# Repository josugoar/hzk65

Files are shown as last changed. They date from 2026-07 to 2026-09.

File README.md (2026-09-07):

# hzk65

<p align="center">
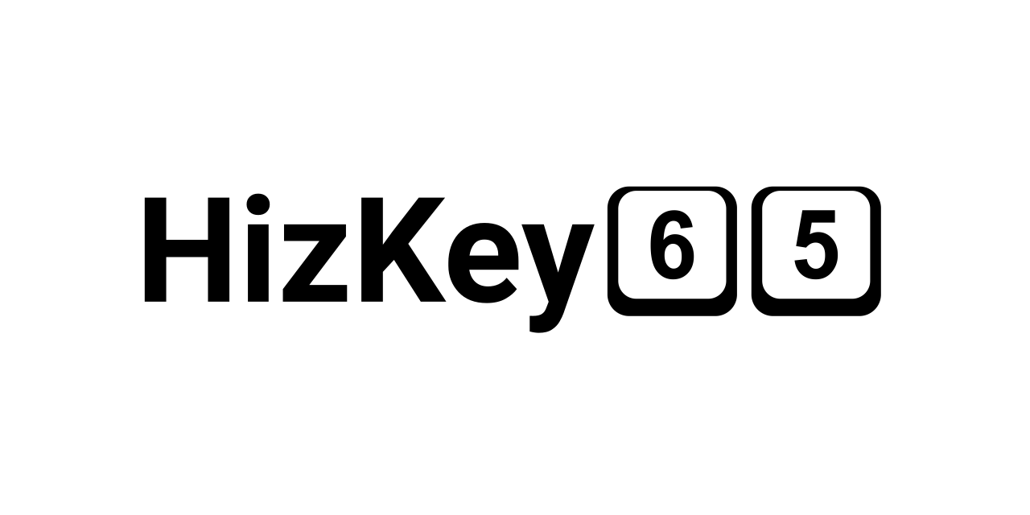
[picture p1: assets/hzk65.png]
hzk65
  
</p>

<h1></h1>

> Modular assembly 65% keyboard

HizKey65 ([/is̻ki/](https://hiztegiak.elhuyar.eus/eu/hizki)) is a modular assembly 65% keyboard with a socketed controller, hot-swap switch sockets, sandwich-mounted case and ANSI layout.

Built with [KiCad](https://www.kicad.org/) and [FreeCAD](https://www.freecad.org/) and manufactured by [JLC Digital Manufacturing](https://jlcpcb.com/).

> [!NOTE]
> Enclose the controller in an acrylic housing or use conformal coating for enhanced protection

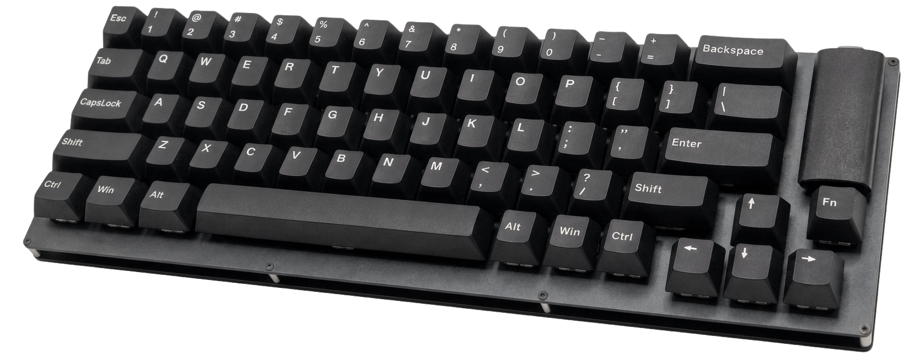
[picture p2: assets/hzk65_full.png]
hzk65_full


## Latest revisions

- hzk65: for Cherry MX compatible switches

  - Rev. A (Hotswappable)

## Layout

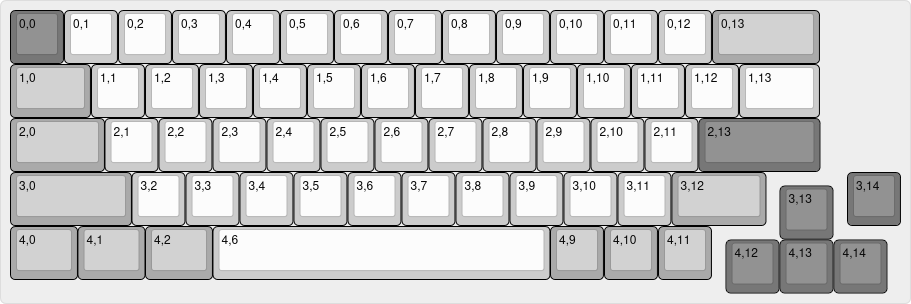
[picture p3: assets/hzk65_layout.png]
hzk65_layout

*[KLE layout](https://www.keyboard-layout-editor.com/##@@_c=%23777777%3B&=0,0&_c=%23cccccc%3B&=0,1&=0,2&=0,3&=0,4&=0,5&=0,6&=0,7&=0,8&=0,9&=0,10&=0,11&=0,12&_c=%23aaaaaa&w:2%3B&=0,13%3B&@_w:1.5%3B&=1,0&_c=%23cccccc%3B&=1,1&=1,2&=1,3&=1,4&=1,5&=1,6&=1,7&=1,8&=1,9&=1,10&=1,11&=1,12&_w:1.5%3B&=1,13%3B&@_c=%23aaaaaa&w:1.75%3B&=2,0&_c=%23cccccc%3B&=2,1&=2,2&=2,3&=2,4&=2,5&=2,6&=2,7&=2,8&=2,9&=2,10&=2,11&_c=%23777777&w:2.25%3B&=2,13%3B&@_c=%23aaaaaa&w:2.25%3B&=3,0&_c=%23cccccc%3B&=3,2&=3,3&=3,4&=3,5&=3,6&=3,7&=3,8&=3,9&=3,10&=3,11&_c=%23aaaaaa&w:1.75%3B&=3,12&_x:1.5&c=%23777777%3B&=3,14%3B&@_y:-0.75&x:14.25%3B&=3,13%3B&@_y:-0.25&c=%23aaaaaa&w:1.25%3B&=4,0&_w:1.25%3B&=4,1&_w:1.25%3B&=4,2&_c=%23cccccc&w:6.25&%2F_rs:180%3B&=4,6&_c=%23aaaaaa%3B&=4,9&=4,10&=4,11%3B&@_y:-0.75&x:13.25&c=%23777777%3B&=4,12&=4,13&=4,14)*

## PCB

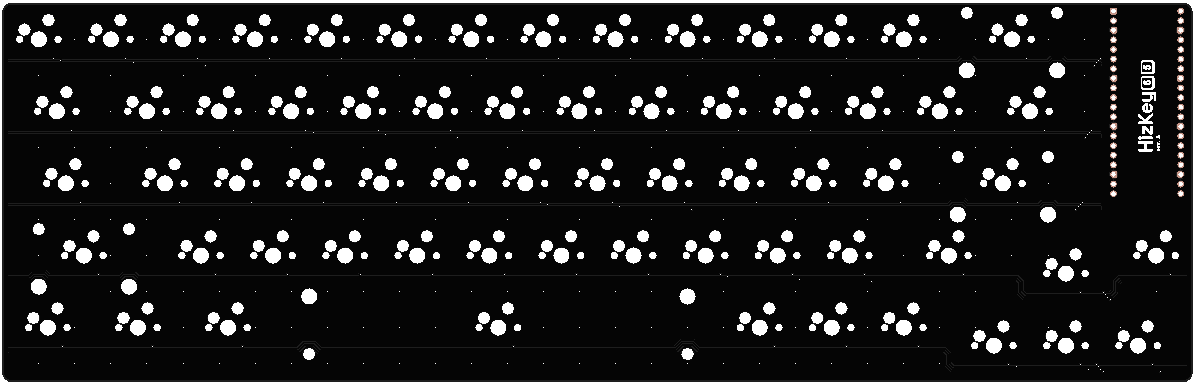
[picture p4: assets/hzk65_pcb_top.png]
hzk65_pcb_top

*Top view*

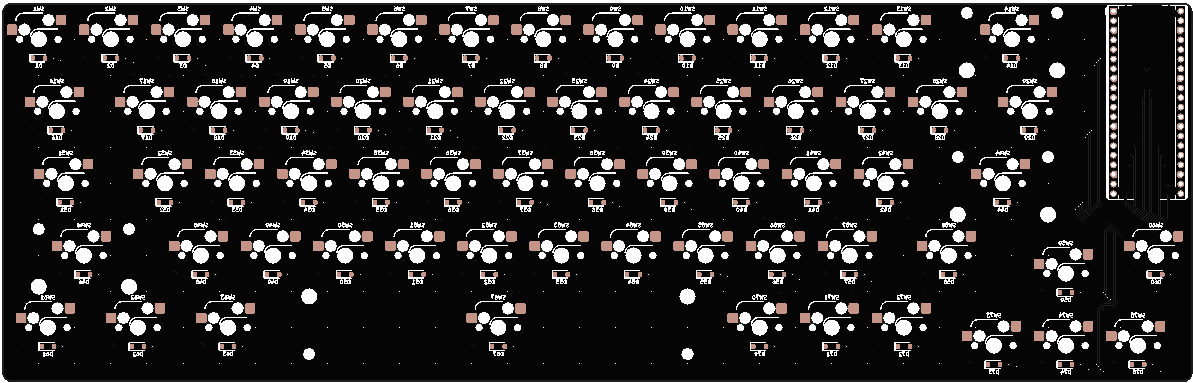
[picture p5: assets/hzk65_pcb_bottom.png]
hzk65_pcb_bottom

*Bottom view*

## Assembly

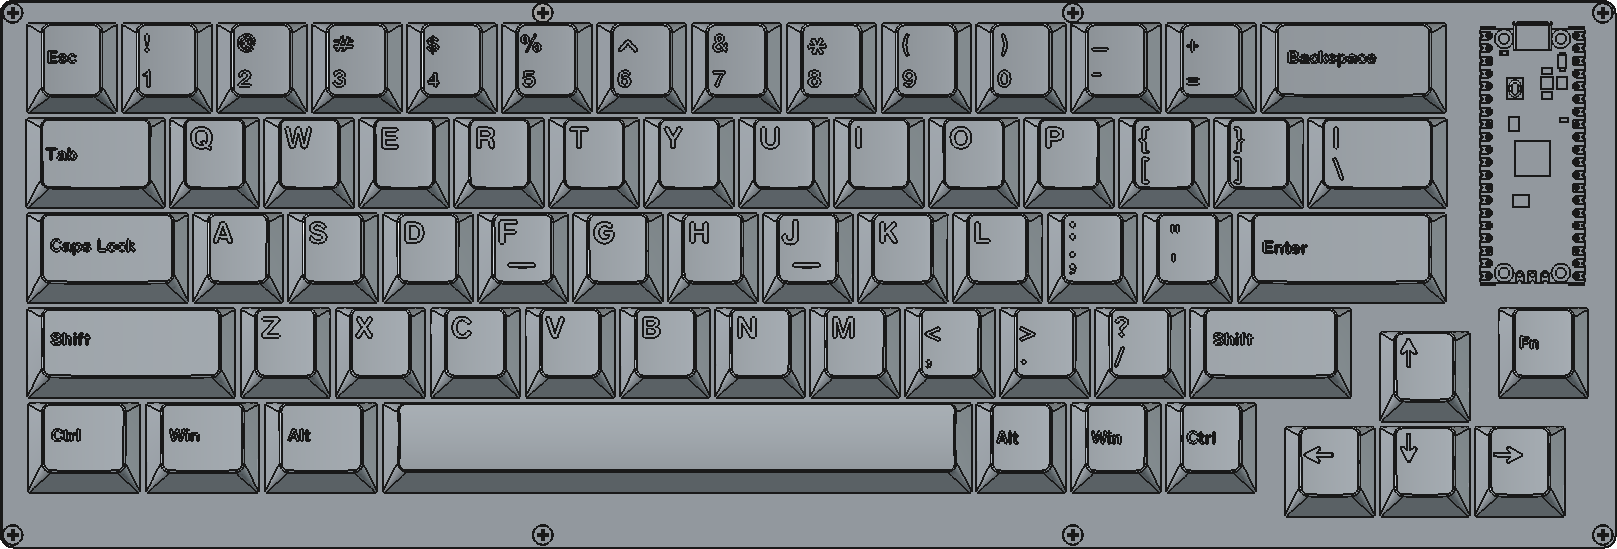
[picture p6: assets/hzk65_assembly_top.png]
hzk65_assembly_top

*Top view*

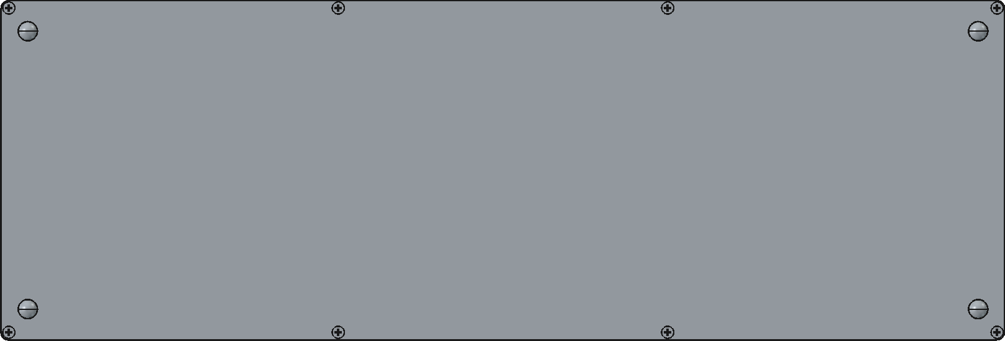
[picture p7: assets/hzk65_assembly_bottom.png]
hzk65_assembly_bottom

*Bottom view*

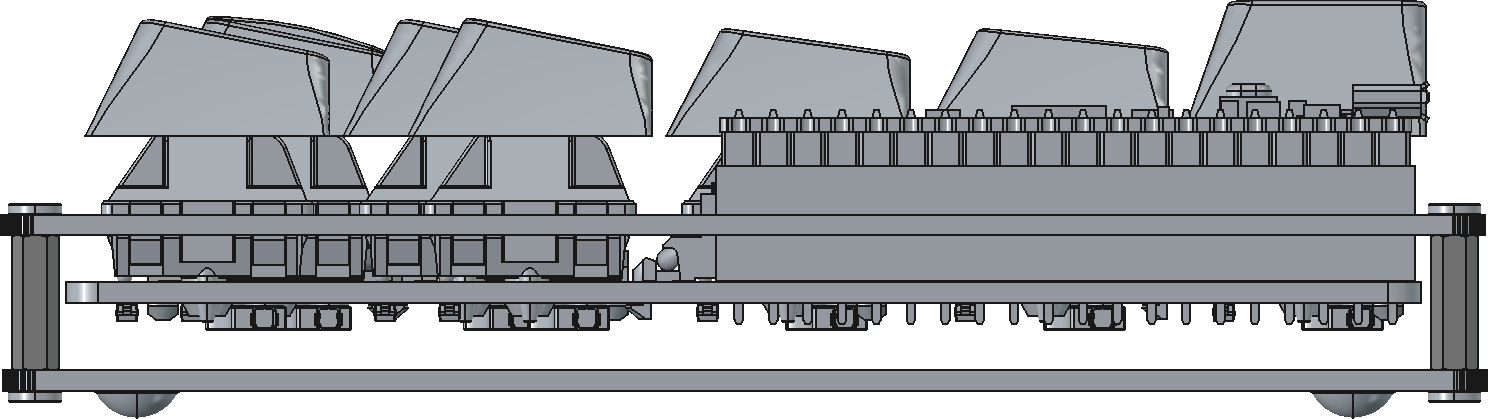
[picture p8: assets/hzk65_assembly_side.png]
hzk65_assembly_side

*Side view*

## Credits

- [CherryMx](https://github.com/hineybush/CherryMX): MX profile keycap 3D models

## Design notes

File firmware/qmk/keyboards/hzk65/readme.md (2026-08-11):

# hzk65

*Modular assembly 65% keyboard*

* Keyboard Maintainer: [Josu](https://github.com/josugoar)
* Hardware Supported: *hzk65*
* Hardware Availability: *https://github.com/josugoar/hzk65*

Make example for this keyboard (after setting up your build environment):

    make hzk65:default

Flashing example for this keyboard:

    make hzk65:default:flash

See the [build environment setup](https://docs.qmk.fm/#/getting_started_build_tools) and the [make instructions](https://docs.qmk.fm/#/getting_started_make_guide) for more information. Brand new to QMK? Start with our [Complete Newbs Guide](https://docs.qmk.fm/#/newbs).

> [!NOTE]
> The hzk65 keyboard directory must be copied to the [qmk_firmware](https://github.com/qmk/qmk_firmware) source tree for compilation

## Bootloader

Enter the bootloader in 3 ways:

* **Bootmagic reset**: Hold down the key at (0,0) in the matrix (usually the top left key or Escape) and plug in the keyboard
* **Physical reset button**: Briefly press the button on the back of the PCB - some may have pads you must short instead
* **Keycode in layout**: Press the key mapped to `QK_BOOT` if it is available

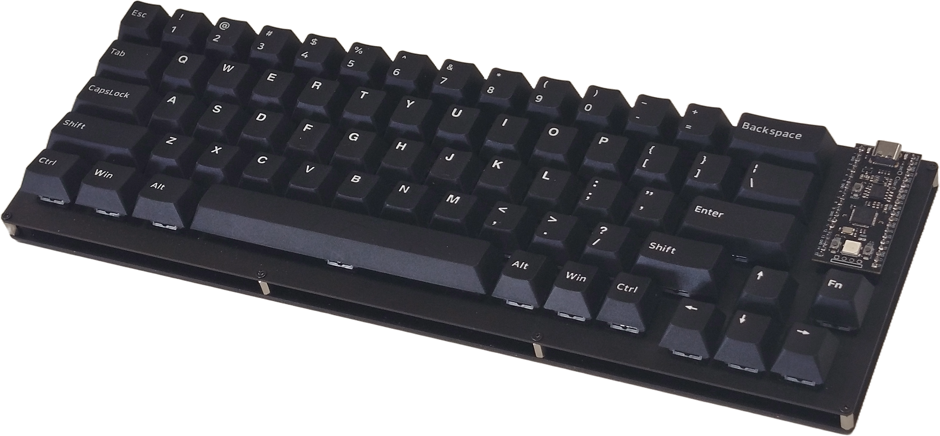
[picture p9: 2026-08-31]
assets/hzk65_pov.png

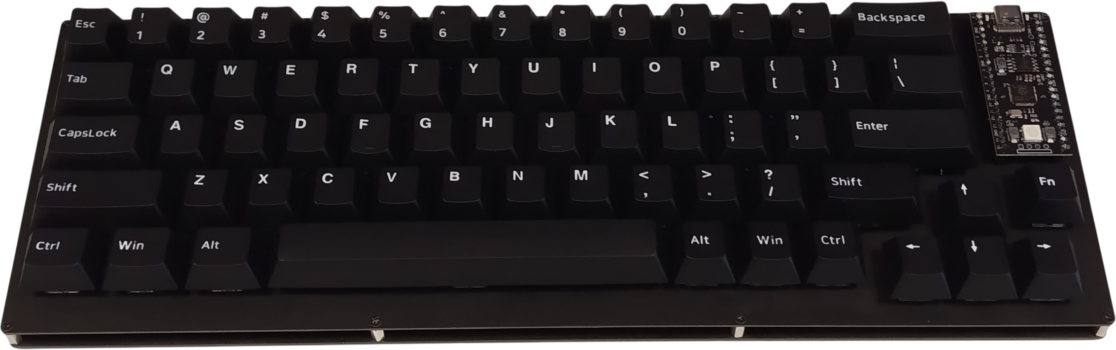
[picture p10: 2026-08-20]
assets/hzk65_top.png

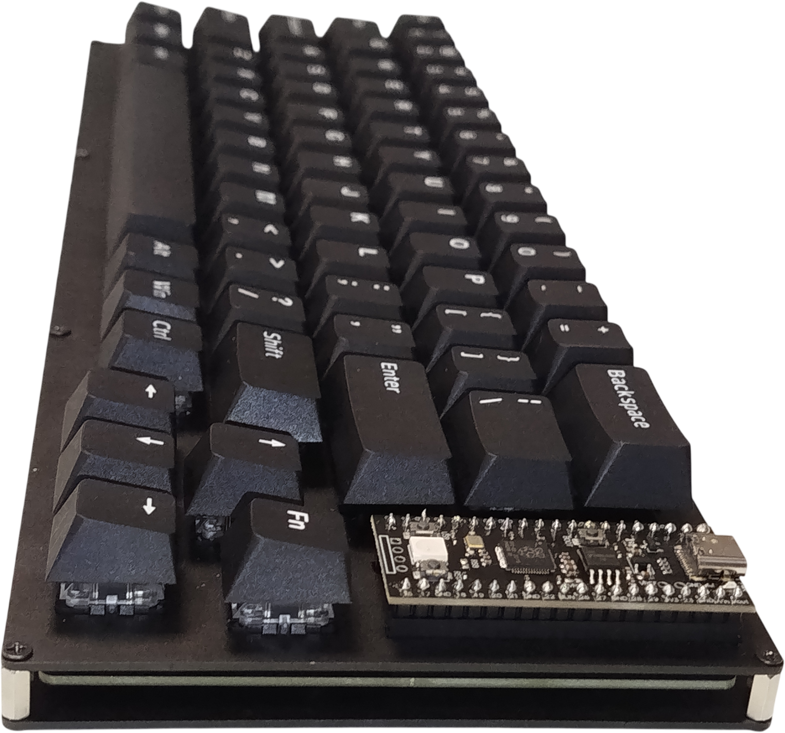
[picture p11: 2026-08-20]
assets/hzk65_side.png

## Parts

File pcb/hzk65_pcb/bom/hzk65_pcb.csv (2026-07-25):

Reference | Qty | Value | DNP | Exclude from BOM | Exclude from Board | Footprint | Datasheet
A1 | 1 | RaspberryPi_Pico |  |  |  | Module:RaspberryPi_Pico_Common_THT | https://datasheets.raspberrypi.com/pico/pico-datasheet.pdf
D1,D2,D3,D4,D5,D6,D7,D8,D9,D10,D11,D12,D13,D14,D16,D17,D18,D19,D20,D21,D22,D23,D24,D25,D26,D27,D28,D29,D31,D32,D33,D34,D35,D36,D37,D38,D39,D40,D41,D42,D44,D46,D48,D49,D50,D51,D52,D53,D54,D55,D56,D57,D58,D59,D60,D61,D62,D63,D67,D70,D71,D72,D73,D74,D75 | 65 | 1N4148 |  |  |  | Diode_SMD:D_SOD-123 | https://assets.nexperia.com/documents/data-sheet/1N4148_1N4448.pdf
SW1,SW2,SW3,SW4,SW5,SW6,SW7,SW8,SW9,SW10,SW11,SW12,SW13,SW17,SW18,SW19,SW20,SW21,SW22,SW23,SW24,SW25,SW26,SW27,SW28,SW32,SW33,SW34,SW35,SW36,SW37,SW38,SW39,SW40,SW41,SW42,SW48,SW49,SW50,SW51,SW52,SW53,SW54,SW55,SW56,SW57,SW59,SW60,SW70,SW71,SW72,SW73,SW74,SW75 | 54 | SW_Push |  |  |  | Switch_Keyboard_Hotswap_Kailh:SW_Hotswap_Kailh_MX_1.00u
SW14 | 1 | SW_Push |  |  |  | Switch_Keyboard_Hotswap_Kailh:SW_Hotswap_Kailh_MX_2.00u
SW16,SW29 | 2 | SW_Push |  |  |  | Switch_Keyboard_Hotswap_Kailh:SW_Hotswap_Kailh_MX_1.50u
SW31,SW58 | 2 | SW_Push |  |  |  | Switch_Keyboard_Hotswap_Kailh:SW_Hotswap_Kailh_MX_1.75u
SW44,SW46 | 2 | SW_Push |  |  |  | Switch_Keyboard_Hotswap_Kailh:SW_Hotswap_Kailh_MX_2.25u
SW61,SW62,SW63 | 3 | SW_Push |  |  |  | Switch_Keyboard_Hotswap_Kailh:SW_Hotswap_Kailh_MX_1.25u
SW67 | 1 | SW_Push |  |  |  | Switch_Keyboard_Hotswap_Kailh:SW_Hotswap_Kailh_MX_6.25u

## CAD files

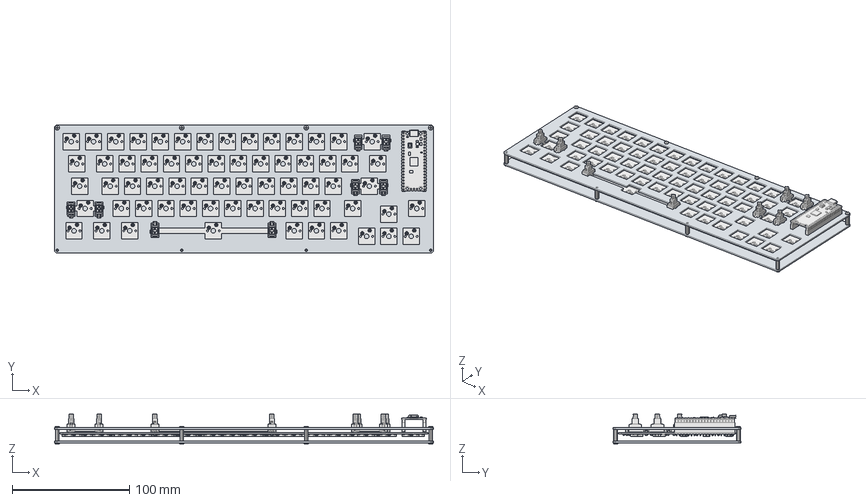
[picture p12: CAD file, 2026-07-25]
mechanical/hzk65.FCStd
323.9 x 109.5 x 25.3 mm
hzk65_switch
hzk65_bottom
hzk65
EJLD_U3_M2_L10_001
EJLD_U3_M2_L10_002
EJLD_U3_M2_L10_003
EJLD_U3_M2_L10_004
EJLD_U3_M2_L10_005
EJLD_U3_M2_L10_006
EJLD_U3_M2_L10_007
EJLD_U3_M2_L10_008
ELSV_S1W_M2_L5_S4_001
ELSV_S1W_M2_L5_S4_002
ELSV_S1W_M2_L5_S4_003
ELSV_S1W_M2_L5_S4_004
ELSV_S1W_M2_L5_S4_005
ELSV_S1W_M2_L5_S4_006
ELSV_S1W_M2_L5_S4_007
ELSV_S1W_M2_L5_S4_008

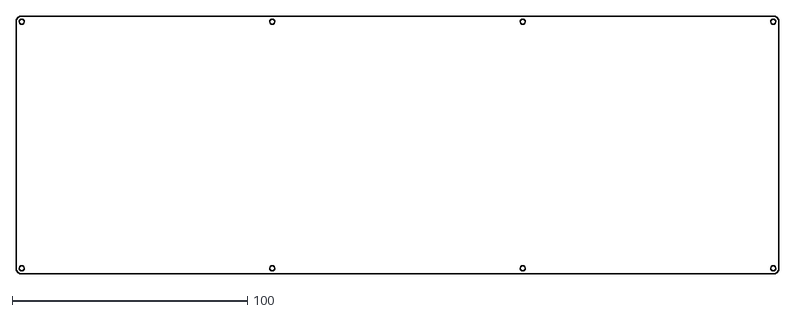
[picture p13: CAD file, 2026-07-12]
mechanical/hzk65_bottom/2d_files/hzk65_bottom.dxf
323.9 x 109.5

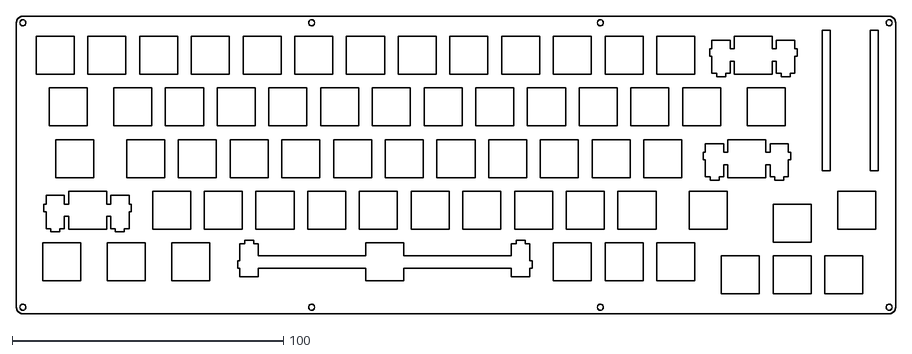
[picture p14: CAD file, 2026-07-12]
mechanical/hzk65_switch/2d_files/hzk65_switch.dxf
323.9 x 109.5

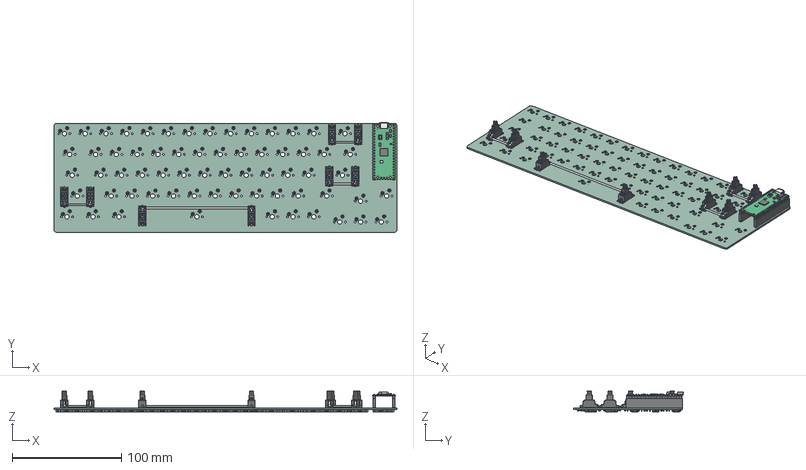
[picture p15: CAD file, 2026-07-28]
pcb/hzk65_pcb/pcb_render/hzk65.step
314.3 x 100.6 x 19.1 mm
SW_Hotswap_Kailh_cp x 65
Stabilizer_Cherry_MX_2u_cp x 3
PinSocket_1x20_KiCad x 2
RaspberryPi_Pico_Module_KiCad
RaspberryPi_Pico_Header_Breakaway_H2.54mm_KiCad x 2
Stabilizer_Cherry_MX_6_25u_cp
D_SOD-123 x 65
hzk65_PCB

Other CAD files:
mechanical/hzk65/3d_files/hzk65.step
mechanical/hzk65_bottom/3d_files/hzk65_bottom.step
mechanical/hzk65_bottom/hzk64_bottom.FCStd
mechanical/hzk65_bottom/pcb_render/hzk65_bottom.step
mechanical/hzk65_switch/3d_files/hzk65_switch.step
mechanical/hzk65_switch/pcb_render/hzk65_switch.step
pcb/hzk65_pcb/pcb_render/hzk65_pcb.step
mechanical/hzk65/hzk65.FCStd
mechanical/hzk65_switch/hzk65_switch.FCStd

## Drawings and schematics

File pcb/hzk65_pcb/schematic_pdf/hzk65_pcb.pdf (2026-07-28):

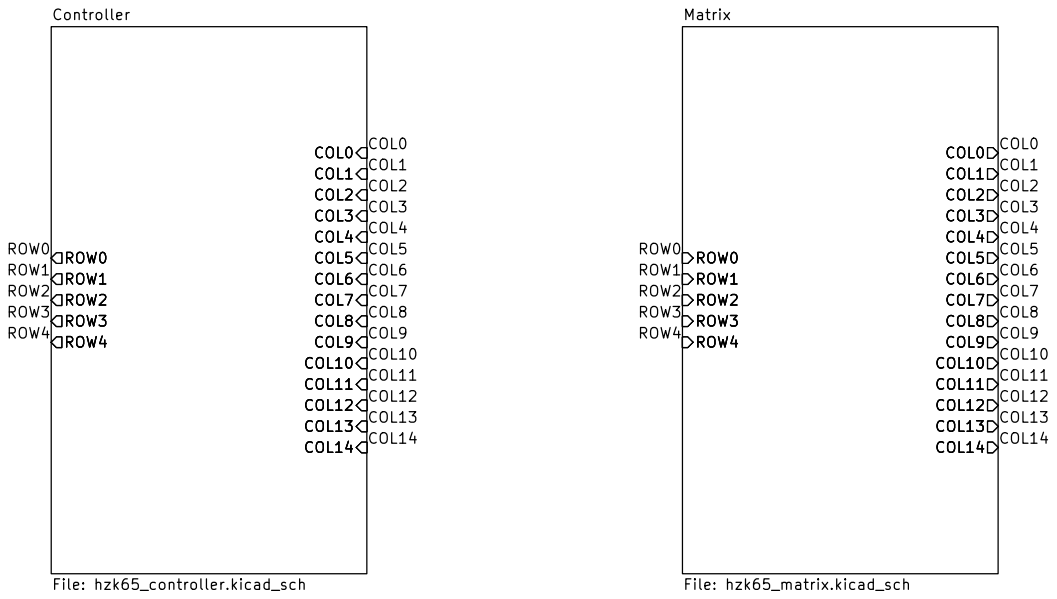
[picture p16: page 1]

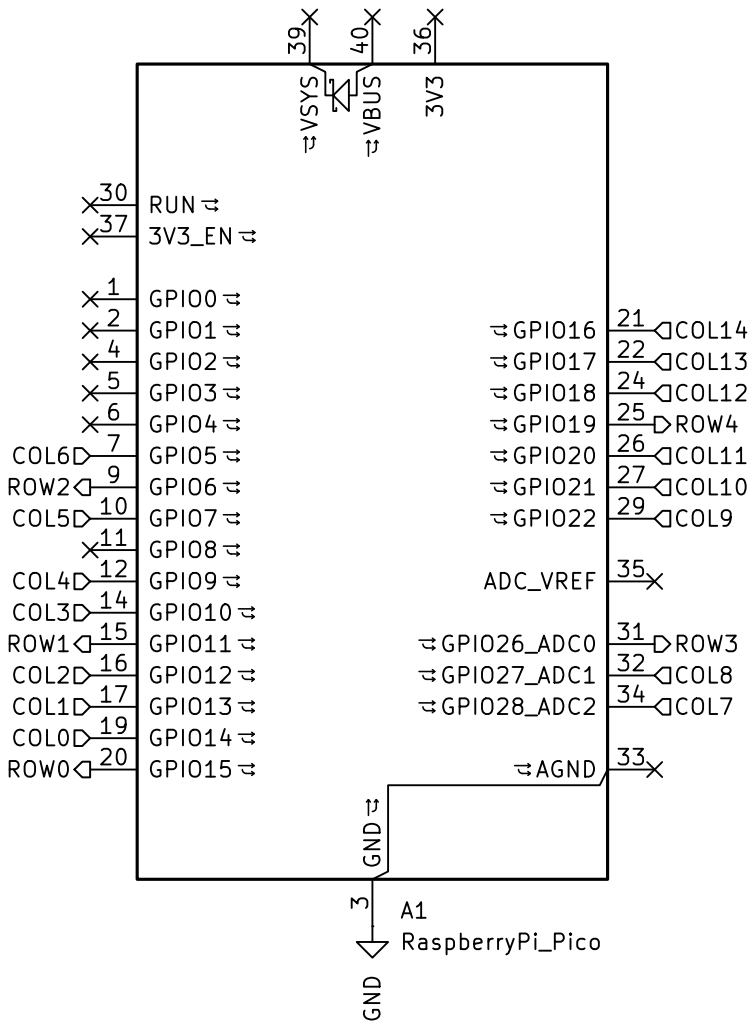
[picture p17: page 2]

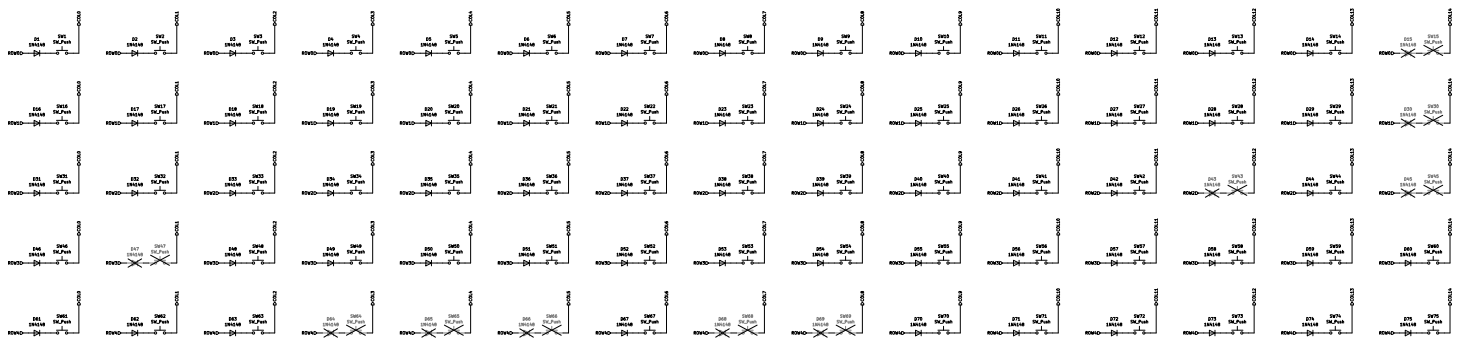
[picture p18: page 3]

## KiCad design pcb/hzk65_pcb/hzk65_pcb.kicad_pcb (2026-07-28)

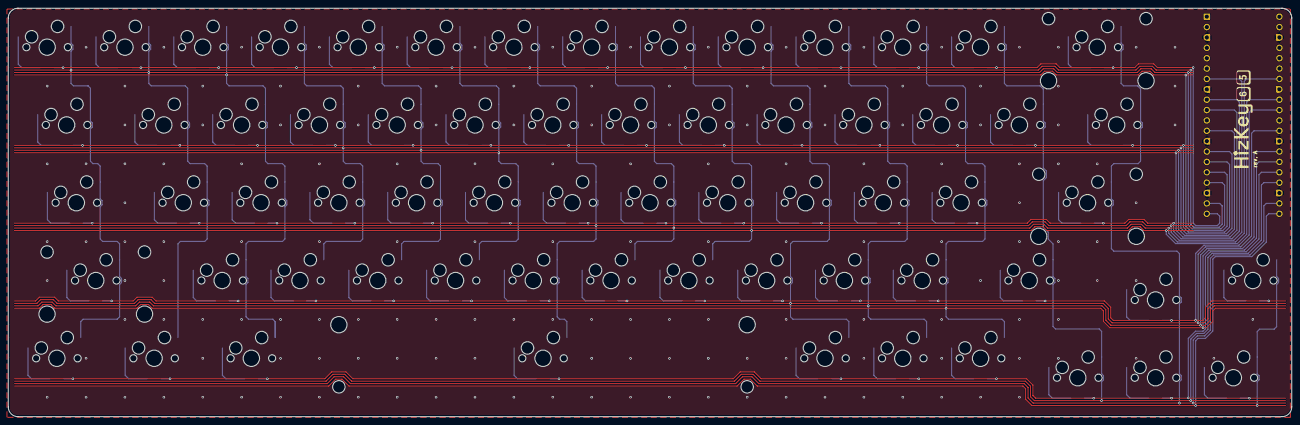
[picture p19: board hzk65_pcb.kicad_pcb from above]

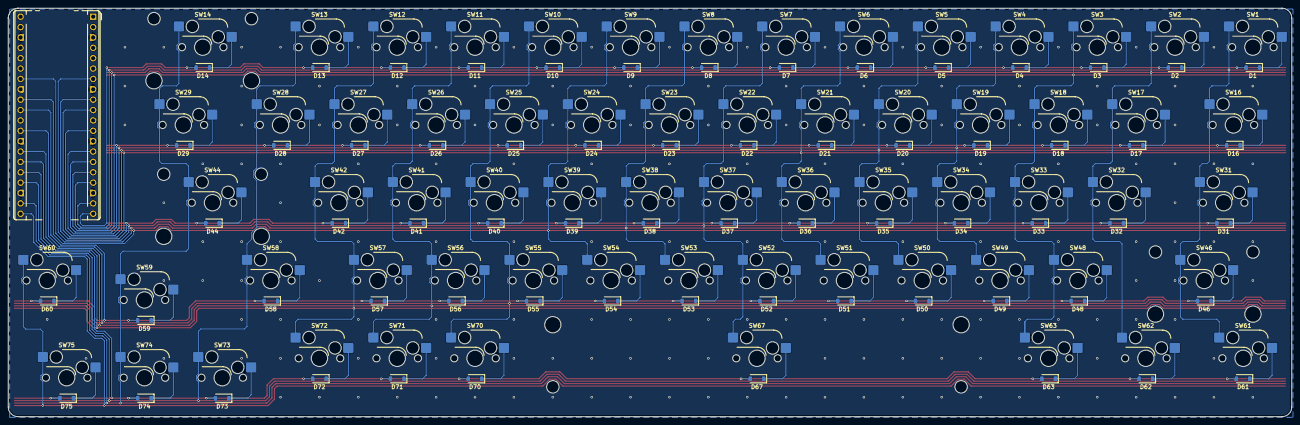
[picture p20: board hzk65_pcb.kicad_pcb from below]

Board: 2 copper layers, 314.3 x 100.0 mm, 135 parts (65 on the bottom side), 86 nets.

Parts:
A1: RaspberryPi_Pico; RaspberryPi_Pico_Common_THT
D1, D2, D3, D4, D5, D6, D7, D8, D9, D10, D11, D12, D13, D14, D16, D17, D18, D19, D20, D21, D22, D23, D24, D25, D26, D27, D28, D29, D31, D32, D33, D34, D35, D36, D37, D38, D39, D40, D41, D42, D44, D46, D48, D49, D50, D51, D52, D53, D54, D55, D56, D57, D58, D59, D60, D61, D62, D63, D67, D70, D71, D72, D73, D74, D75: 1N4148; D_SOD-123
H14, H46: Stabilizer_Cherry_MX_2.00u
H44: m; Stabilizer_Cherry_MX_2.00u
H67: Stabilizer_Cherry_MX_6.25u
SW1, SW2, SW3, SW4, SW5, SW6, SW7, SW8, SW9, SW10, SW11, SW12, SW13, SW17, SW18, SW19, SW20, SW21, SW22, SW23, SW24, SW25, SW26, SW27, SW28, SW32, SW33, SW34, SW35, SW36, SW37, SW38, SW39, SW40, SW41, SW42, SW48, SW49, SW50, SW51, SW52, SW53, SW54, SW55, SW56, SW57, SW59, SW60, SW70, SW71, SW72, SW73, SW74, SW75: SW_Push; SW_Hotswap_Kailh_MX_1.00u
SW14: SW_Push; SW_Hotswap_Kailh_MX_2.00u
SW16, SW29: SW_Push; SW_Hotswap_Kailh_MX_1.50u
SW31, SW58: SW_Push; SW_Hotswap_Kailh_MX_1.75u
SW44, SW46: SW_Push; SW_Hotswap_Kailh_MX_2.25u
SW61, SW62, SW63: SW_Push; SW_Hotswap_Kailh_MX_1.25u
SW67: SW_Push; SW_Hotswap_Kailh_MX_6.25u

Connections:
/COL0: A1.19 (GPIO14), SW1.2, SW16.2, SW31.2, SW46.2, SW61.2
/COL1: A1.17 (GPIO13), SW2.2, SW17.2, SW32.2, SW62.2
/COL2: A1.16 (GPIO12), SW3.2, SW18.2, SW33.2, SW48.2, SW63.2
/COL3: A1.14 (GPIO10), SW4.2, SW19.2, SW34.2, SW49.2
/COL4: A1.12 (GPIO9), SW5.2, SW20.2, SW35.2, SW50.2
/COL5: A1.10 (GPIO7), SW6.2, SW21.2, SW36.2, SW51.2
/COL6: A1.7 (GPIO5), SW7.2, SW22.2, SW37.2, SW52.2, SW67.2
/COL7: A1.34 (GPIO28_ADC2), SW8.2, SW23.2, SW38.2, SW53.2
/COL8: A1.32 (GPIO27_ADC1), SW9.2, SW24.2, SW39.2, SW54.2
/COL9: A1.29 (GPIO22), SW10.2, SW25.2, SW40.2, SW55.2, SW70.2
/COL10: A1.27 (GPIO21), SW11.2, SW26.2, SW41.2, SW56.2, SW71.2
/COL11: A1.26 (GPIO20), SW12.2, SW27.2, SW42.2, SW57.2, SW72.2
/COL12: A1.24 (GPIO18), SW13.2, SW28.2, SW58.2, SW73.2
/COL13: A1.22 (GPIO17), SW14.2, SW29.2, SW44.2, SW59.2, SW74.2
/COL14: A1.21 (GPIO16), SW60.2, SW75.2
/ROW0: A1.20 (GPIO15), D1.2 (A), D2.2 (A), D3.2 (A), D4.2 (A), D5.2 (A), D6.2 (A), D7.2 (A), D8.2 (A), D9.2 (A), D10.2 (A), D11.2 (A), D12.2 (A), D13.2 (A), D14.2 (A)
/ROW1: A1.15 (GPIO11), D16.2 (A), D17.2 (A), D18.2 (A), D19.2 (A), D20.2 (A), D21.2 (A), D22.2 (A), D23.2 (A), D24.2 (A), D25.2 (A), D26.2 (A), D27.2 (A), D28.2 (A), D29.2 (A)
/ROW2: A1.9 (GPIO6), D31.2 (A), D32.2 (A), D33.2 (A), D34.2 (A), D35.2 (A), D36.2 (A), D37.2 (A), D38.2 (A), D39.2 (A), D40.2 (A), D41.2 (A), D42.2 (A), D44.2 (A)
/ROW3: A1.31 (GPIO26_ADC0), D46.2 (A), D48.2 (A), D49.2 (A), D50.2 (A), D51.2 (A), D52.2 (A), D53.2 (A), D54.2 (A), D55.2 (A), D56.2 (A), D57.2 (A), D58.2 (A), D59.2 (A), D60.2 (A)
/ROW4: A1.25 (GPIO19), D61.2 (A), D62.2 (A), D63.2 (A), D67.2 (A), D70.2 (A), D71.2 (A), D72.2 (A), D73.2 (A), D74.2 (A), D75.2 (A)
GND: A1.3 (GND), A1.8 (GND), A1.13 (GND), A1.18 (GND), A1.23 (GND), A1.28 (GND), A1.38 (GND)
unnamed: D1.1 (K), SW1.1
unnamed: D2.1 (K), SW2.1
unnamed: D3.1 (K), SW3.1
unnamed: D4.1 (K), SW4.1
unnamed: D5.1 (K), SW5.1
unnamed: D6.1 (K), SW6.1
unnamed: D7.1 (K), SW7.1
unnamed: D8.1 (K), SW8.1
unnamed: D9.1 (K), SW9.1
unnamed: D10.1 (K), SW10.1
unnamed: D11.1 (K), SW11.1
unnamed: D12.1 (K), SW12.1
unnamed: D13.1 (K), SW13.1
unnamed: D14.1 (K), SW14.1
unnamed: D16.1 (K), SW16.1
unnamed: D17.1 (K), SW17.1
unnamed: D18.1 (K), SW18.1
unnamed: D19.1 (K), SW19.1
unnamed: D20.1 (K), SW20.1
unnamed: D21.1 (K), SW21.1
unnamed: D22.1 (K), SW22.1
unnamed: D23.1 (K), SW23.1
unnamed: D24.1 (K), SW24.1
unnamed: D25.1 (K), SW25.1
unnamed: D26.1 (K), SW26.1
unnamed: D27.1 (K), SW27.1
unnamed: D28.1 (K), SW28.1
unnamed: D29.1 (K), SW29.1
unnamed: D31.1 (K), SW31.1
unnamed: D32.1 (K), SW32.1
unnamed: D33.1 (K), SW33.1
unnamed: D34.1 (K), SW34.1
unnamed: D35.1 (K), SW35.1
unnamed: D36.1 (K), SW36.1
unnamed: D37.1 (K), SW37.1
unnamed: D38.1 (K), SW38.1
unnamed: D39.1 (K), SW39.1
unnamed: D40.1 (K), SW40.1
unnamed: D41.1 (K), SW41.1
unnamed: D42.1 (K), SW42.1
unnamed: D44.1 (K), SW44.1
unnamed: D46.1 (K), SW46.1
unnamed: D48.1 (K), SW48.1
unnamed: D49.1 (K), SW49.1
unnamed: D50.1 (K), SW50.1
unnamed: D51.1 (K), SW51.1
unnamed: D52.1 (K), SW52.1
unnamed: D53.1 (K), SW53.1
unnamed: D54.1 (K), SW54.1
unnamed: D55.1 (K), SW55.1
unnamed: D56.1 (K), SW56.1
unnamed: D57.1 (K), SW57.1
unnamed: D58.1 (K), SW58.1
unnamed: D59.1 (K), SW59.1
unnamed: D60.1 (K), SW60.1
unnamed: D61.1 (K), SW61.1
unnamed: D62.1 (K), SW62.1
unnamed: D63.1 (K), SW63.1
unnamed: D67.1 (K), SW67.1
unnamed: D70.1 (K), SW70.1
unnamed: D71.1 (K), SW71.1
unnamed: D72.1 (K), SW72.1
unnamed: D73.1 (K), SW73.1
unnamed: D74.1 (K), SW74.1
unnamed: D75.1 (K), SW75.1

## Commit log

2026-06-21 Add kicad schematic
    [controller.kicad_sch, gr65.kicad_pcb, gr65.kicad_sch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]
2026-06-21 Rename sheets
    [gr65.kicad_sch, gr65_controller.kicad_sch, gr65_matrix.kicad_sch]
2026-06-21 Update matrix positions
    [gr65_matrix.kicad_sch]
2026-06-28 Add bom
    [gr65.csv]
2026-07-04 Update bom
    [gr65.csv]
2026-07-04 Remove spaces
    [gr65.csv]
2026-07-04 Remove quotes
    [gr65.csv]
2026-07-05 Update pcb with exploded layout
    [gr65.kicad_pcb, gr65_matrix.kicad_sch]
2026-07-05 Fix 3d models
    [hzk65.kicad_pcb]
2026-07-05 Exclude footprint drcs
2026-07-05 Add logo silkscreens
    [hzk65.kicad_pcb]
2026-07-05 Add oshw logo reference
    [hzk65.kicad_pcb]
2026-07-05 Fix drc via and silkscreen warnings
    [hzk65.kicad_pcb]
2026-07-06 Don't pick and place mcu
    [hzk65_controller.kicad_sch]
2026-07-06 Route all switches
    [hzk65.kicad_pcb]
2026-07-08 Add copper pours
    [hzk65.kicad_pcb]
2026-07-08 Add stitching vias
    [hzk65.kicad_pcb]
2026-07-10 Add plate step files
    [hzk65_bottom.step, hzk65_switch.step]
2026-07-10 Add plate dxf files
    [hzk65_bottom.dxf, hzk65_switch.dxf]
2026-07-11 Use 2.2 mm screw holes
    [hzk65_bottom.dxf, hzk65_switch.dxf]
2026-07-11 Add kad json for plate generation
2026-07-11 Add fr4 bottom plate pcb
    [hzk65_bottom.kicad_pcb]
2026-07-11 Add fr4 switch plate pcb
    [hzk65_switch.kicad_pcb]
2026-07-11 Handle drc exclusions
    [hzk65.kicad_pcb]
2026-07-11 Update stitching via grid
    [hzk65.kicad_pcb]
2026-07-11 Add temporary socket connectors for plate
    [hzk65.kicad_pcb]
2026-07-11 Update models with new mcu cutout
    [hzk65_bottom.step, hzk65_switch.dxf, hzk65_switch.step]
2026-07-11 Update switch plate with new cutout
    [hzk65.kicad_pcb, hzk65_switch.kicad_pcb]
2026-07-12 Update socket tolerances
2026-07-12 Add dxf with better tolerances
    [hzk65_switch.dxf]
2026-07-12 Update fr4 plate with tols
    [hzk65_switch.kicad_pcb]
2026-07-12 Fix incorrect screw diameters
    [hzk65_bottom.dxf, hzk65_bottom.step, hzk65_switch.dxf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]
2026-07-22 Update key matrix disposition
    [hzk65_matrix.kicad_sch]
2026-07-22 Use bus routing for rows and cols
    [hzk65.kicad_pcb]
2026-07-25 Update gpios
    [hzk65_controller.kicad_sch]
2026-07-25 Finish routing board
    [hzk65.kicad_pcb]
2026-07-25 Generate gerbers
    [hzk65.kicad_pcb]
2026-07-25 Switch to standard project layout
    [hzk64_bottom.FCStd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]
2026-07-25 Update pcb outputs
    [hzk65-B_Cu.gbr, hzk65-B_Mask.gbr, hzk65-B_Paste.gbr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]
2026-07-25 Add bottom case exports
    [hzk65_bottom-B_Cu.gbr, hzk65_bottom-B_Mask.gbr, hzk65_bottom-B_Paste.gbr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]
2026-07-25 Update switch plate exports
    [hzk65_switch-B_Cu.gbr, hzk65_switch-B_Mask.gbr, hzk65_switch-B_Paste.gbr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]
2026-07-25 Add assembly
    [hzk65.FCStd]
2026-07-25 Fix rev graphic positioning
    [hzk65-B_Cu.gbr, hzk65-B_Mask.gbr, hzk65-B_Paste.gbr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]
2026-07-25 Reorganize directory structure
    [hzk64_bottom.FCStd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]
2026-07-25 Add screws to model
    [hzk65.FCStd]
2026-07-25 Update mechanical component references
    [hzk65.FCStd]
2026-07-26 Improve symmetrical routing
    [hzk65-B_Cu.gbr, hzk65-B_Mask.gbr, hzk65-B_Paste.gbr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]
2026-07-26 Improve routing for aesthetics
    [hzk65-B_Cu.gbr, hzk65-B_Mask.gbr, hzk65-B_Paste.gbr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]
2026-07-28 Move bottom dxf to 2d_files
    [hzk65_bottom.dxf]
2026-07-28 Move switch dxf to 2d_files
    [hzk65_switch.dxf]
2026-07-28 Update pcb step name
    [hzk65.step]
2026-07-28 Add drill files for manufacturing
    [hzk65-B_Cu.gbl, hzk65-B_Mask.gbs, hzk65-B_Paste.gbp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]
2026-07-28 Add pcb suffix to pcb project
    [hzk65-B_Cu.gbl, hzk65-B_Cu.gbr, hzk65-B_Mask.gbr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]
2026-07-28 Make pcb suffixes consistent
    [hzk65_controller.kicad_sch, hzk65_matrix.kicad_sch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]
2026-08-02 Assemble keyboard model and add FreeCAD and step files to lfs
    [hzk64_bottom.FCStd, hzk65.step, hzk65_bottom.step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]
2026-08-02 Add short-circuit note
2026-08-19 Update to new layout
    [hzk65.FCStd, hzk65.step]
2026-09-04 Add case variants
2026-09-07 Fix esc key
